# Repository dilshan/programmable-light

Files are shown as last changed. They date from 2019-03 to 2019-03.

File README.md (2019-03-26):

# Programmable Light Controller

Finished version of programmable light controller
Programmable light is a low cost and easy to build LED light controller. The main objective of this project is to design a maintenance free light which automatically on and off at the predetermined time of the day.

This light controller is based on *ATmega8* microcontroller and *DS1307* real time clock. It is designed to handle commonly available 24V - 7W LED modules. 

This is [certified open source hardware project](https://certification.oshwa.org/lk000002.html). All the design files, documentation, firmware source code are available to download at the [project source repository](https://github.com/dilshan/programmable-light). All the content of this project are distributed under the terms of the following license: 

* Hardware License: [CC BY 4.0](https://creativecommons.org/licenses/by/4.0/)
* Software License: [MIT](https://github.com/dilshan/programmable-light/blob/master/LICENSE)
* Documentation License: [CC BY 4.0](https://creativecommons.org/licenses/by/4.0/)

LK000002 (https://certification.oshwa.org/lk000002.html)

For more details check [project documentation at GitHub](https://github.com/dilshan/programmable-light/wiki).

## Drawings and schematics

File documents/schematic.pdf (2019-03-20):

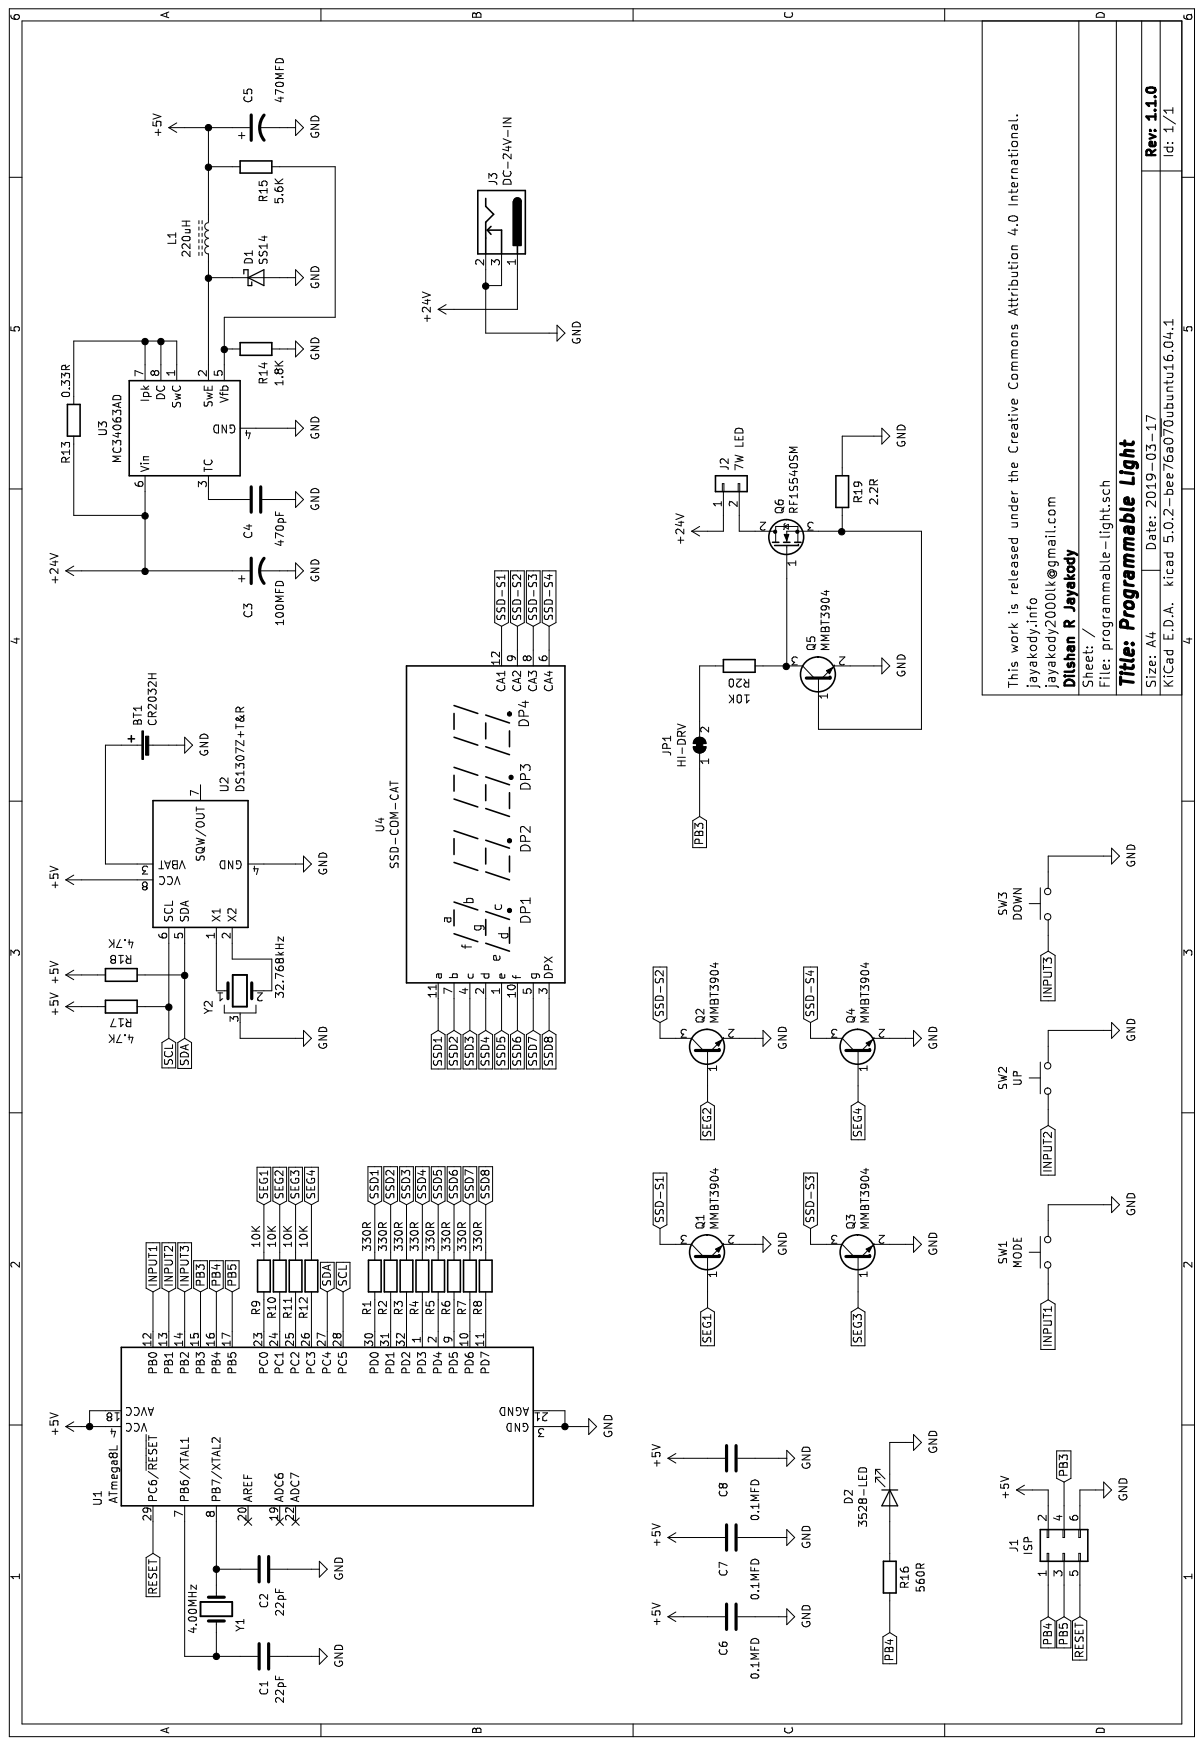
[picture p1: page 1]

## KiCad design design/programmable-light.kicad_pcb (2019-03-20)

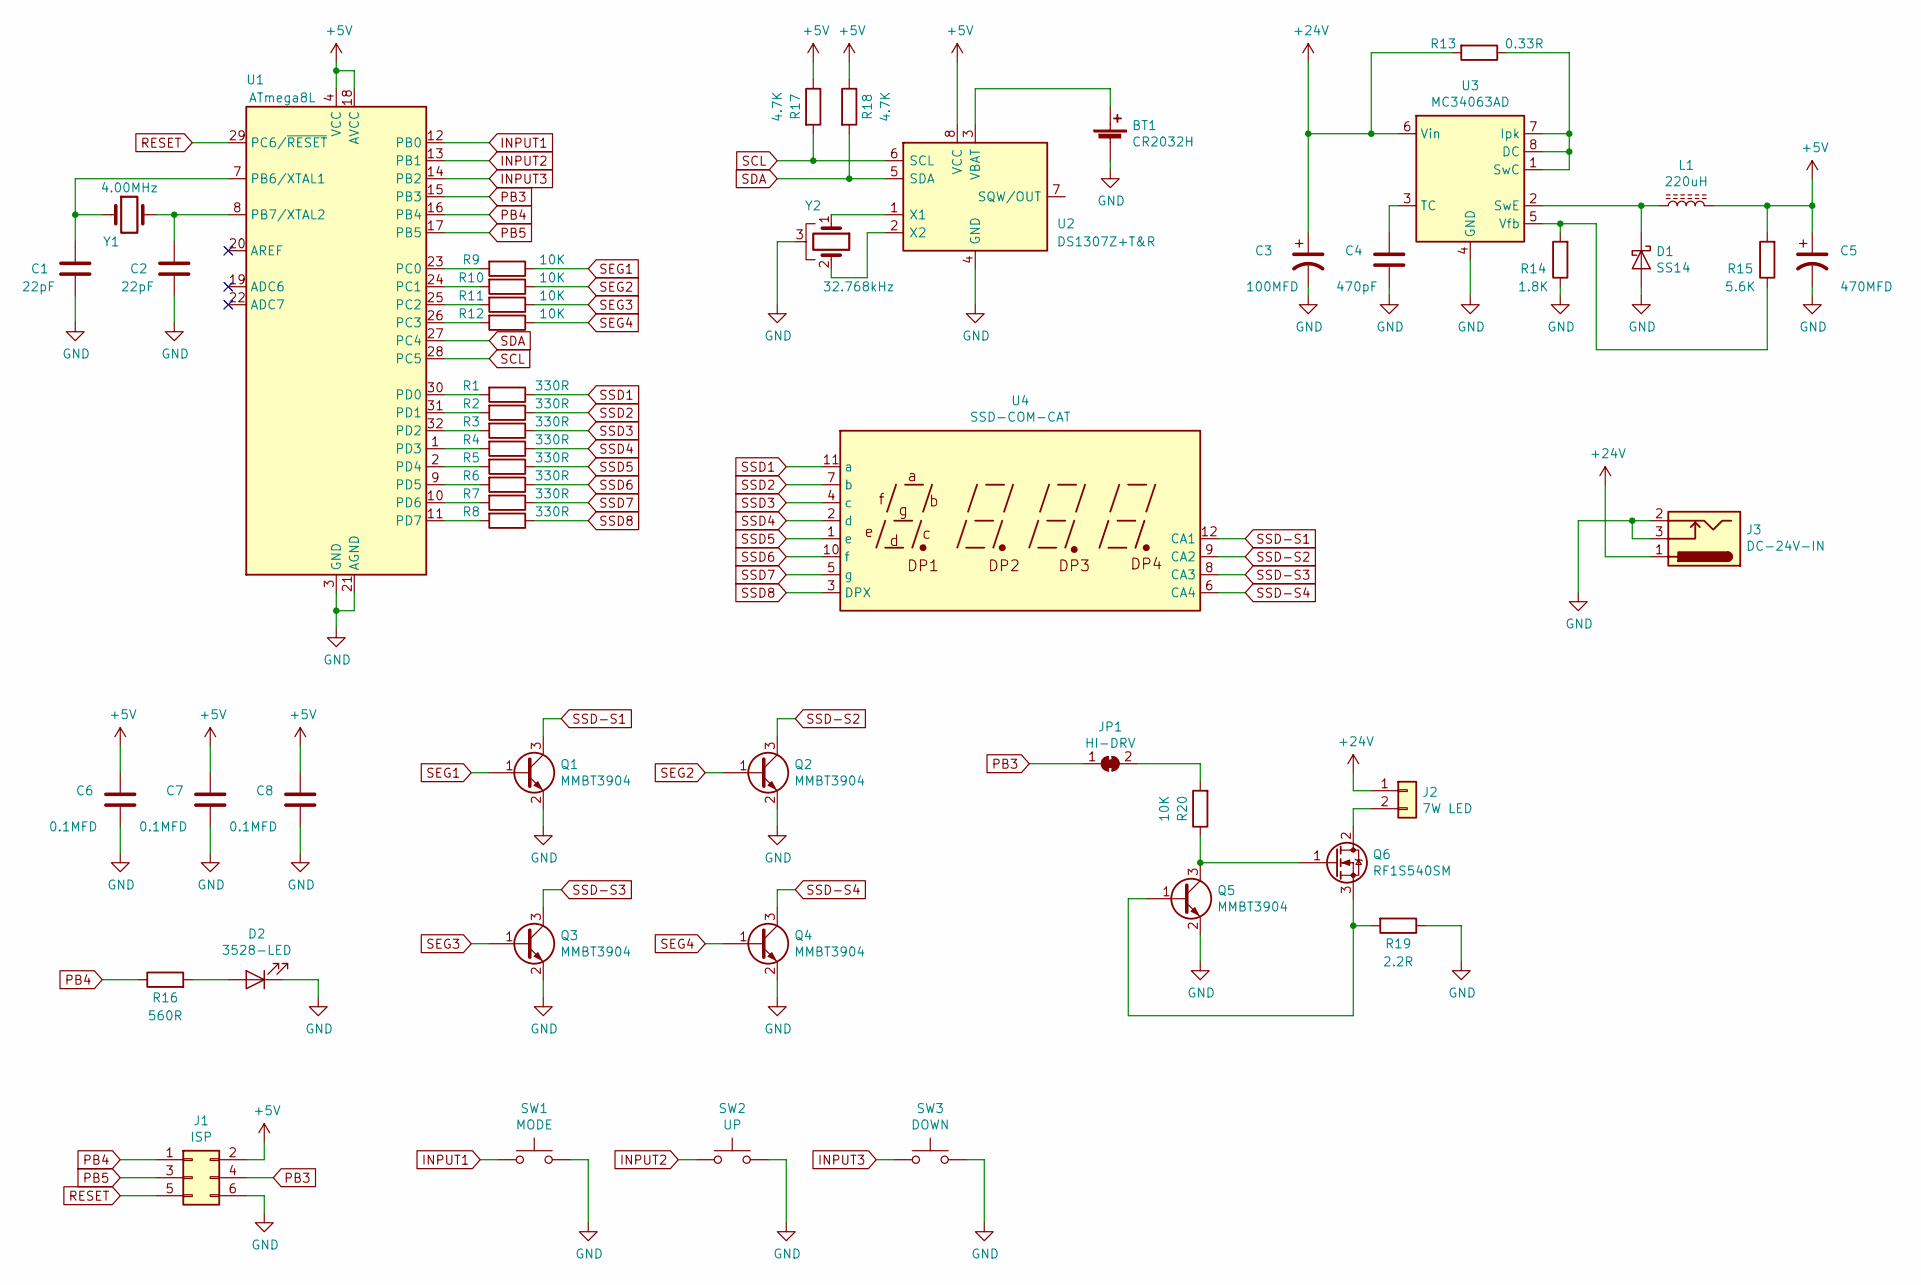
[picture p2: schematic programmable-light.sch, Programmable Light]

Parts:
BT1: CR2032H; BatteryHolder_Keystone_104_1x23mm
C1, C2: 22pF; C_0805_2012Metric
C3: 100MFD; CP_Elec_6.3x5.4
C4: 470pF; C_0805_2012Metric
C5: 470MFD; CP_Elec_10x10.5
C6, C7, C8: 0.1MFD; C_0805_2012Metric
D1: SS14; D_SMA
D2: 3528-LED; LED_1210_3225Metric
J1: ISP; PinHeader_2x03_P2.54mm_Vertical
J2: 7W LED; PhoenixContact_MCV_1,5_2-G-3.81_1x02_P3.81mm_Vertical
J3: DC-24V-IN; BarrelJack_Horizontal
JP1: HI-DRV; SolderJumper-2_P1.3mm_Bridged2Bar_RoundedPad1.0x1.5mm
L1: 220uH; L_Taiyo-Yuden_NR-80xx
Q1, Q2, Q3, Q4, Q5: MMBT3904; SOT-23
Q6: RF1S540SM; TO-263-2
R1, R2, R3, R4, R5, R6, R7, R8: 330R; R_0805_2012Metric
R9, R10, R11, R12, R20: 10K; R_0805_2012Metric
R13: 0.33R; R_2512_6332Metric
R14: 1.8K; R_0805_2012Metric
R15: 5.6K; R_0805_2012Metric
R16: 560R; R_0805_2012Metric
R17, R18: 4.7K; R_0805_2012Metric
R19: 2.2R; R_Axial_DIN0516_L15.5mm_D5.0mm_P20.32mm_Horizontal
SW1: MODE; SW_PUSH_6mm
SW2: UP; SW_PUSH_6mm
SW3: DOWN; SW_PUSH_6mm
U1: ATmega8L; TQFP-32_7x7mm_P0.8mm
U2: DS1307Z+T&R; SOIC-8_3.9x4.9mm_P1.27mm
U3: MC34063AD; SOIC-8_3.9x4.9mm_P1.27mm
U4: SSD-COM-CAT; CA56-12CGKWA
Y1: 4.00MHz; Crystal_SMD_HC49-SD
Y2: 32.768kHz; Crystal_C26-LF_D2.1mm_L6.5mm_Horizontal_1EP_style2

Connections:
+5V: C5.1, C6.1, C7.1, C8.1, J1.2, L1.2, R15.2, R17.1, R18.1, U1.4 (VCC), U1.6 (VCC), U1.18 (AVCC), U2.8 (VCC)
+24V: C3.1, J2.1, J3.1, R13.2, U3.6 (Vin)
GND: BT1.2 (-), C1.2, C2.2, C3.2, C4.2, C5.2, C6.2, C7.2, C8.2, D1.2 (A), D2.1 (K), J1.6, J3.2, J3.3, Q1.2 (E), Q2.2 (E), Q3.2 (E), Q4.2 (E), Q5.2 (E), R14.1, R19.1, SW1.2, SW2.2, SW3.2, U1.3 (GND), U1.5 (GND), U1.21 (AGND), U2.4 (GND), U3.4 (GND), Y2.3
INPUT1: SW1.1, U1.12 (PB0)
INPUT2: SW2.1, U1.13 (PB1)
INPUT3: SW3.1, U1.14 (PB2)
unnamed: BT1.1 (+), U2.3 (VBAT)
unnamed: C1.1, U1.7 (PB6/XTAL1), Y1.1
unnamed: C2.1, U1.8 (PB7/XTAL2), Y1.2
unnamed: C4.1, U3.3 (TC)
unnamed: D1.1 (K), L1.1, U3.2 (SwE)
unnamed: D2.2 (A), R16.2
unnamed: J2.2, Q6.2 (D)
unnamed: JP1.2 (B), R20.2
unnamed: Q5.1 (B), Q6.3 (S), R19.2
unnamed: Q5.3 (C), Q6.1 (G), R20.1
unnamed: R1.2, U1.30 (PD0)
unnamed: R2.2, U1.31 (PD1)
unnamed: R3.2, U1.32 (PD2)
unnamed: R4.2, U1.1 (PD3)
unnamed: R5.2, U1.2 (PD4)
unnamed: R6.2, U1.9 (PD5)
unnamed: R7.2, U1.10 (PD6)
unnamed: R8.2, U1.11 (PD7)
unnamed: R9.2, U1.23 (PC0)
unnamed: R10.2, U1.24 (PC1)
unnamed: R11.2, U1.25 (PC2)
unnamed: R12.2, U1.26 (PC3)
unnamed: R13.1, U3.1 (SwC), U3.7 (Ipk), U3.8 (DC)
unnamed: R14.2, R15.1, U3.5 (Vfb)
unnamed: U2.1 (X1), Y2.1
unnamed: U2.2 (X2), Y2.2
PB3: J1.4, JP1.1 (A), U1.15 (PB3)
PB4: J1.1, R16.1, U1.16 (PB4)
PB5: J1.3, U1.17 (PB5)
RESET: J1.5, U1.29 (PC6/~RESET)
SCL: R17.2, U1.28 (PC5), U2.6 (SCL)
SDA: R18.2, U1.27 (PC4), U2.5 (SDA)
SEG1: Q1.1 (B), R9.1
SEG2: Q2.1 (B), R10.1
SEG3: Q3.1 (B), R11.1
SEG4: Q4.1 (B), R12.1
SSD1: R1.1, U4.11 (a)
SSD2: R2.1, U4.7 (b)
SSD3: R3.1, U4.4 (c)
SSD4: R4.1, U4.2 (d)
SSD5: R5.1, U4.1 (e)
SSD6: R6.1, U4.10 (f)
SSD7: R7.1, U4.5 (g)
SSD8: R8.1, U4.3 (DPX)
SSD-S1: Q1.3 (C), U4.12 (CA1)
SSD-S2: Q2.3 (C), U4.9 (CA2)
SSD-S3: Q3.3 (C), U4.8 (CA3)
SSD-S4: Q4.3 (C), U4.6 (CA4)

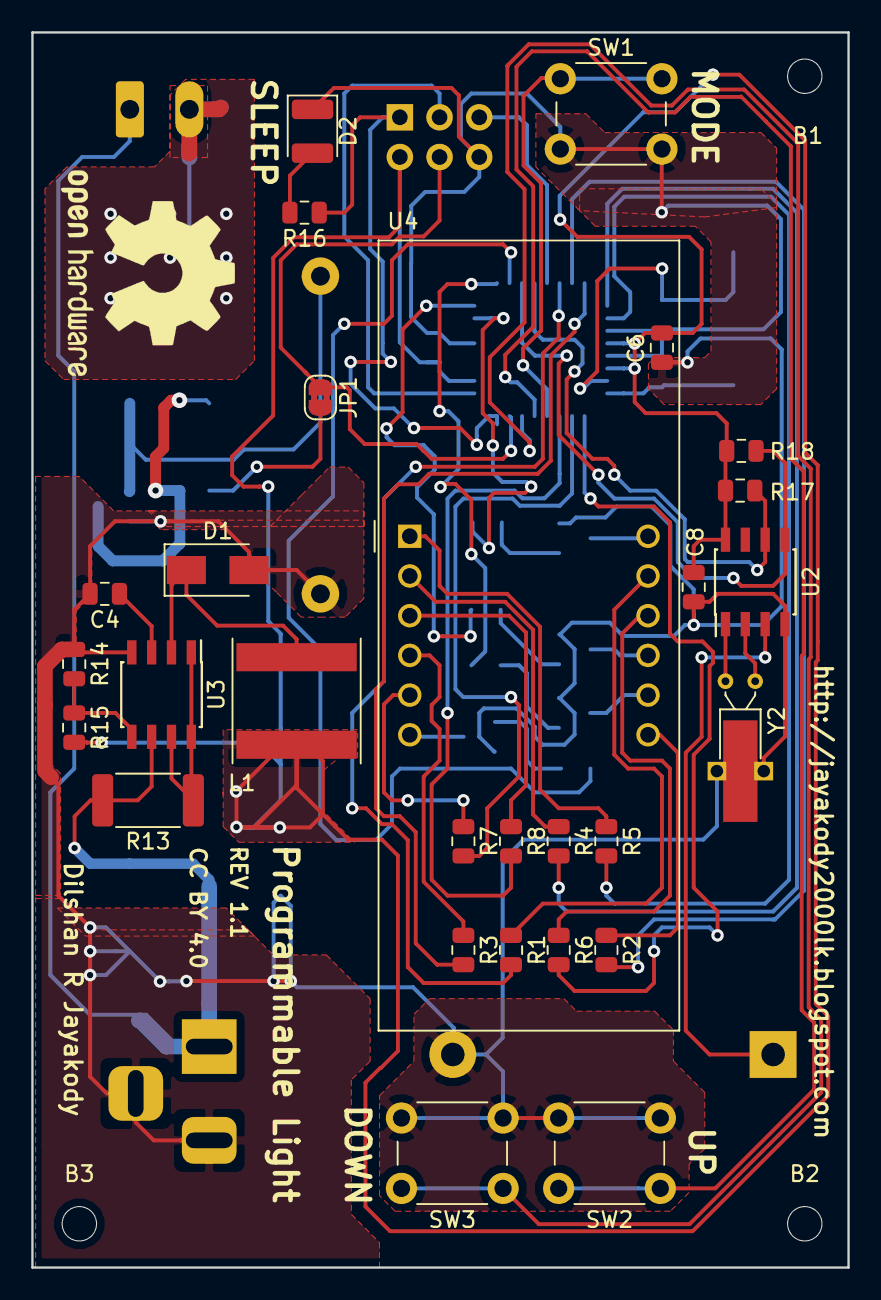
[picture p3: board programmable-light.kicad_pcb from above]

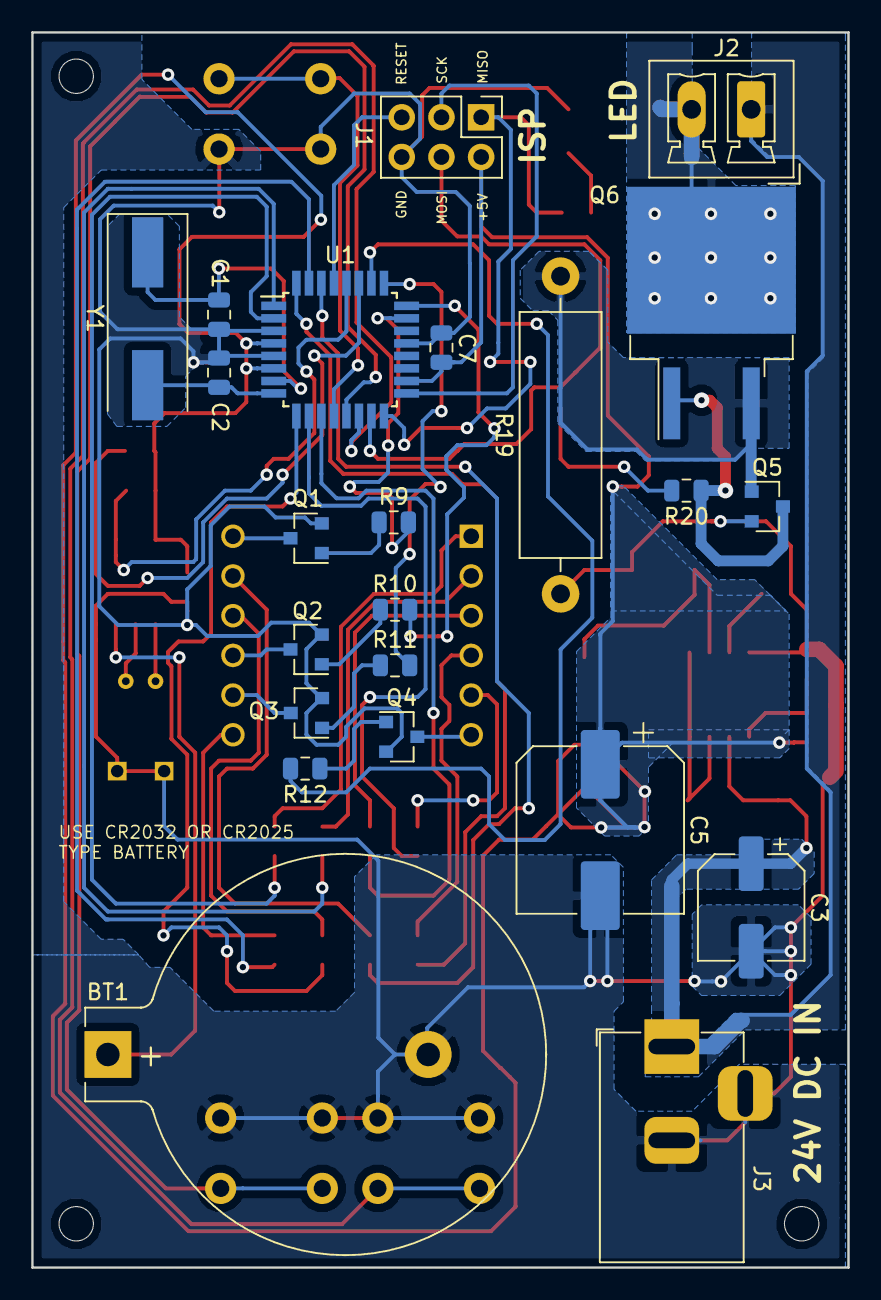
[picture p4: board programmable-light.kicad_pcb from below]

Board: 2 copper layers, 52.2 x 79.0 mm, 54 parts (23 on the bottom side), 54 nets.

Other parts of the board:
B1, B2, B3: M2-1; MountingHole_2.2mm_M2

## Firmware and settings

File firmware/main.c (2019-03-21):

/*************************************************************************
* Title:	ATmega8 Firmware for programmable light controller.
* Author:	Dilshan R Jayakody <jayakody2000lk@gmail.com>
* Project:	Programmable LED controller.
* Homepage:	https://github.com/dilshan/programmable-light
* File:     main.c
* Info:		Main firmware module with applicaion entry point.
* Compiler: AVR GCC 5.4.0 (AVR 8-bit GNU Toolchain 3.6.1)
* Target:   ATmega8L / ATmega8A
**************************************************************************/

#include "sysbasedef.h"
#include "main.h"
#include "displaymodule.h"
#include "rtcmodule.h"
#include "memmodule.h"
#include "timemodule.h"

#include <avr/io.h>
#include <util/delay.h>	
#include <avr/interrupt.h>

INT main(VOID)
{
	UCHAR currentButtonState = 0x07;
	UCHAR lastButtonState = 0x07;
	UCHAR optionButtonCycles = 0;
	
	initSystem();
	
	// Load user defined start and end time from EEPROM.
	readTimeFromMemory(&_startTime, 0);
	readTimeFromMemory(&_endTime, 4);
	
	// Check for valid start and end time.
	IS_VALID_EEPROM_VALUE(_startTime.hours);
	IS_VALID_EEPROM_VALUE(_startTime.minutes);
	IS_VALID_EEPROM_VALUE(_startTime.seconds);
	
	IS_VALID_EEPROM_VALUE(_endTime.hours);
	IS_VALID_EEPROM_VALUE(_endTime.minutes);
	IS_VALID_EEPROM_VALUE(_endTime.seconds);
	
	while (1) 
    {
		currentButtonState = (PINB & 0x07);
		
		// Check for <option button> press event.
		if(IS_BUTTON_PRESSED(currentButtonState, 0x01, lastButtonState))
		{
			optionButtonCycles = 0;
			_ssdMode = SSD_DISPLAY_TIME;
			startSleepTimer();
		}
		
		// Check for <up button> press event.
		if(IS_BUTTON_PRESSED(currentButtonState, 0x02, lastButtonState))
		{
			optionButtonCycles = 0;
			_ssdMode = SSD_DISPLAY_START;
			startSleepTimer();
		}
		
		// Check for <down button> press event.
		if(IS_BUTTON_PRESSED(currentButtonState, 0x04, lastButtonState))
		{
			optionButtonCycles = 0;
			_ssdMode = SSD_DISPLAY_END;
			startSleepTimer();
		}
		
		// Clear timer if system is idle for long time.
		if(!_sleepTimer)
		{
			_ssdMode = SSD_DISPLAY_NONE;
		}
		
		// Count <option button> hold time.
		if((currentButtonState & 0x01) == 0x00)
		{
			optionButtonCycles++;
		}
		
		// Long press of <option button> should open settings menu.
		if(optionButtonCycles > LONG_PRESS_LIMIT)
		{
			optionButtonCycles = 0;

			updateSleepLED(FALSE);
			showConfigurationOption();
			
			// Update system time immediately. 
			getSystemTime(&_sysTime);
			
			// Restore blink status and related variables.
			setEditSegment(NO_EDIT_SEGMENT);
			setBlickState(TRUE);
			
			// Reset button status.
			currentButtonState = 0x07;
			lastButtonState = currentButtonState;
			continue;
		}
		
		// Update seven segment display based on current display mode.
		switch(_ssdMode)
		{
			case SSD_DISPLAY_TIME:
				sysTimeToDisplayBuffer(&_sysTime, &_displayBuffer);
				updateSleepLED(FALSE);
				break;
			case SSD_DISPLAY_NONE:
				// Clear entire display buffer and shutdown seven segment display.
				clearDisplay(_displayBuffer.valueBuffer, SSD_SIZE);
				updateSleepLED(TRUE);
				_displayBuffer.decimalPoint = 0xFF;
				break;
			case SSD_DISPLAY_START:
				sysTimeToDisplayBuffer(&_startTime, &_displayBuffer);
				updateSleepLED(FALSE);
				_displayBuffer.decimalPoint = 0x01;
				break;
			case SSD_DISPLAY_END:
				sysTimeToDisplayBuffer(&_endTime, &_displayBuffer);
				updateSleepLED(FALSE);
				_displayBuffer.decimalPoint = 0x01;
				break;
		}
		
		lastButtonState = currentButtonState;
		
		_delay_ms(60);
    }
}

/*************************************************************************
 Set state of the sleep LED.
 
 isActive: Set this parameter to TRUE to turn on the LED.
 
 Return: None
*************************************************************************/
VOID updateSleepLED(UCHAR isActive)
{
	if((isActive == TRUE) && (_isLightActive == FALSE))
	{
		PORTB |= (1 << PB4);
	}
	else
	{
		PORTB &= ~(1 << PB4);
	}
}

/*************************************************************************
 Function to edit specified time data structure.
 
 editBuffer: Instance of the time structure to modify.
 
 Return: None
*************************************************************************/
VOID editTimeValue(PTIME editBuffer)
{
	UCHAR editSegmentId = 0;
	UCHAR tempSeconds;
	UCHAR currentButtonState;
	UCHAR lastButtonState = 0x07;
	UCHAR maxNumber;
	
	// Activate edit mode in display buffer.
	setEditSegment(editSegmentId);
	_isBlink = TRUE;
	_blinkState = TRUE;
	
	// Set seconds to odd number to activate the decimal indicator.
	tempSeconds = editBuffer->seconds;
	editBuffer->seconds = 1;
	sysTimeToDisplayBuffer(editBuffer, &_displayBuffer);
	
	// Wait until user release the pushed button(s).
	waitForButtonRelease();
	startSleepTimer();
	
	while(1)
	{
		currentButtonState = (PINB & 0x07);
		
		// Clear timer if system is idle for long time.
		if(!_sleepTimer)
		{
			// Exit edit mode without saving the changes.
			setEditSegment(NO_EDIT_SEGMENT);
			setBlickState(FALSE);
			_blinkCounter = 0;
			_isBlink = FALSE;
			// Restore the values of time data structure.
			editBuffer->seconds = tempSeconds;
			return;
		}
		
		// Check for <option button> press event.
		if(IS_BUTTON_PRESSED(currentButtonState, 0x01, lastButtonState))
		{
			startSleepTimer();
			
			if(editSegmentId < 3)
			{
				// Move to next segment.
				setEditSegment(++editSegmentId);
				
				// If hour is beyond 20hr we need to correct 2nd digit of the existing hour.
				if((editSegmentId == 1) && (_displayBuffer.valueBuffer[0] == 2) && (_displayBuffer.valueBuffer[1] >= 4))
				{
					_displayBuffer.valueBuffer[1] = 3;
				}
			}
			else
			{
				// Exit edit mode.
				setEditSegment(NO_EDIT_SEGMENT);
				setBlickState(FALSE);
				_blinkCounter = 0;
				_isBlink = FALSE;
				// Update time structure with modified value.
				editBuffer->hours = _displayBuffer.valueBuffer[1] + (_displayBuffer.valueBuffer[0] * 10);
				editBuffer->minutes = _displayBuffer.valueBuffer[3] + (_displayBuffer.valueBuffer[2] * 10);
				editBuffer->seconds = tempSeconds;
				return;
			}
		}
		
		// Check for <up button> press event.
		if(IS_BUTTON_PRESSED(currentButtonState, 0x02, lastButtonState))
		{
			startSleepTimer();
			
			switch(editSegmentId)
			{
				case 0:
					// Modify first digit of the hour and it allows only 0, 1 and 2.
					_displayBuffer.valueBuffer[0] = (_displayBuffer.valueBuffer[0] < 2) ? (_displayBuffer.valueBuffer[0] + 1) : 0;
					break;
				case 1:
					// Modify second digit of the hour. If first digit is 2 then this allows only 0..3, otherwise this allows 0..9
					maxNumber = (_displayBuffer.valueBuffer[0] == 2) ? 3 : 9;
					_displayBuffer.valueBuffer[1] = (_displayBuffer.valueBuffer[1] < maxNumber) ? (_displayBuffer.valueBuffer[1] + 1) : 0;
					break;
				case 2:
					// Modify first digit of the minutes.
					_displayBuffer.valueBuffer[2] = (_displayBuffer.valueBuffer[2] < 5) ? (_displayBuffer.valueBuffer[2] + 1) : 0;
					break;
				case 3:
					// Modify second digit of the minutes.
					_displayBuffer.valueBuffer[3] = (_displayBuffer.valueBuffer[3] < 9) ? (_displayBuffer.valueBuffer[3] + 1) : 0;
					break;
			}
		}
		
		// Check for <down button> press event.
		if(IS_BUTTON_PRESSED(currentButtonState, 0x04, lastButtonState))
		{
			startSleepTimer();
			
			switch(editSegmentId)
			{
				case 0:
					// Modify first digit of the hour and it allows only 0, 1 and 2.
					_displayBuffer.valueBuffer[0] = (_displayBuffer.valueBuffer[0] != 0) ? (_displayBuffer.valueBuffer[0] - 1) : 2;
					break;
				case 1:
					// Modify second digit of the hour. If first digit is 2 then this allows only 0..3, otherwise this allows 0..9
					maxNumber = (_displayBuffer.valueBuffer[0] == 2) ? 3 : 9;
					_displayBuffer.valueBuffer[1] = (_displayBuffer.valueBuffer[1] != 0) ? (_displayBuffer.valueBuffer[1] - 1) : maxNumber;
					break;
				case 2:
					// Modify first digit of the minutes.
					_displayBuffer.valueBuffer[2] = (_displayBuffer.valueBuffer[2] != 0) ? (_displayBuffer.valueBuffer[2] - 1) : 5;
					break;
				case 3:
					// Modify second digit of the minutes.
					_displayBuffer.valueBuffer[3] = (_displayBuffer.valueBuffer[3] != 0) ? (_displayBuffer.valueBuffer[3] - 1) : 9;
					break;
			}
		}
		
		lastButtonState = currentButtonState;
		_delay_ms(50);
	}
}

/*************************************************************************
 Function to handle options menu and related user inputs.
 
 Return: None
*************************************************************************/
VOID showConfigurationOption()
{
	MENU_MODE currentMode = SSD_MENU_TIME;
	UCHAR currentButtonState;
	UCHAR lastButtonState = 0x07;

	// Update display buffer with current mode (SSD_MENU_TIME).
	textToDisplay('S','Y','S',' ', &_displayBuffer);
	
	// Wait until user release the pushed button(s).
	waitForButtonRelease();
	startSleepTimer();
	
	// Start main service loop to handle options related activities.
	while(1)
	{
		currentButtonState = (PINB & 0x07);
		
		// Check for menu timeouts to clear the menu.
		if(!_sleepTimer)
		{
			return;
		}
		
		// Check for <option button> press event.
		if(IS_BUTTON_PRESSED(currentButtonState, 0x01, lastButtonState))
		{
			startSleepTimer();
			
			switch(currentMode)
			{
				case SSD_MENU_TIME:
					// Configure RTC with modified value.
					editTimeValue(&_sysTime);
					setSystemTime(&_sysTime);
					break;
				case SSD_MENU_ON_TIME:
					editTimeValue(&_startTime);
					saveTimeToMemory(&_startTime, 0);
					break;
				case SSD_MENU_OFF_TIME:
					editTimeValue(&_endTime);
					saveTimeToMemory(&_endTime, 4);
					break;
				case SSD_MENU_EXIT:
					// Exit from options menu.
					return;
			}
			
			// Reset button status.
			currentButtonState = 0x07;
			lastButtonState = currentButtonState;
			continue;
		}
		
		// Check for <up button> press event.
		if(IS_BUTTON_PRESSED(currentButtonState, 0x02, lastButtonState))
		{
			startSleepTimer();
			
			switch(currentMode)
			{
				case SSD_MENU_TIME:
					currentMode = SSD_MENU_ON_TIME;
					break;
				case SSD_MENU_ON_TIME:
					currentMode = SSD_MENU_OFF_TIME;
					break;
				case SSD_MENU_OFF_TIME:
					currentMode = SSD_MENU_EXIT;
					break;
				case SSD_MENU_EXIT:
					currentMode = SSD_MENU_TIME;
					break;
			}
		}
		
		// Check for <down button> press event.
		if(IS_BUTTON_PRESSED(currentButtonState, 0x04, lastButtonState))
		{
			startSleepTimer();
			
			switch(currentMode)
			{
				case SSD_MENU_TIME:
					currentMode = SSD_MENU_EXIT;
					break;
				case SSD_MENU_ON_TIME:
					currentMode = SSD_MENU_TIME;
					break;
				case SSD_MENU_OFF_TIME:
					currentMode = SSD_MENU_ON_TIME;
					break;
				case SSD_MENU_EXIT:
					currentMode = SSD_MENU_OFF_TIME;
					break;
			}
		}
			
		// Update seven segment display based on current menu mode.
		switch(currentMode)
		{
			case SSD_MENU_TIME:
				textToDisplay('S','Y','S',' ', &_displayBuffer);
				break;
			case SSD_MENU_ON_TIME:
				textToDisplay('O','N',' ',' ', &_displayBuffer);
				break;
			case SSD_MENU_OFF_TIME:
				textToDisplay('O','F','F',' ', &_displayBuffer);
				break;
			case SSD_MENU_EXIT:
				textToDisplay(' ','-','-',' ', &_displayBuffer);
				break;
		}
		
		lastButtonState = currentButtonState;
		_delay_ms(50);
	}
}

/*************************************************************************
 Interrupt service routine for Timer2. This timer is mainly used to call 
 RTC with specific intervals to update the system time.
 
 Return: None
*************************************************************************/
ISR(TIMER2_OVF_vect)
{
	// Disable timer2 interrupt and start requesting data from RTC.
	TIMSK &= ~( 1 << TOIE2);
	
	if((++_rtcRefreshCounter) == 20)
	{
		getSystemTime(&_sysTime);
		
		// Check for light on condition.
		_isLightActive = isLightActive(&_sysTime, &_startTime, &_endTime);
		if(_isLightActive == TRUE)
		{
			// Turn on master light.
			PORTB |= (1 << PB3);
		}
		else 
		{
			// Turn off master light.
			PORTB &= ~(1 << PB3);
		}
		
		_rtcRefreshCounter = 0;
	}
	
	if(_isBlink == TRUE)
	{
		if((++_blinkCounter) == 10)
		{
			_blinkState = ~_blinkState;
			setBlickState(_blinkState);
			_blinkCounter = 0;
		}
	}
	
	// Reset timer2 counter and enable the interrupt.
	TIMSK |= (1 << TOIE2);
	TCNT2 = 0;
}

/*************************************************************************
 Interrupt service routine for Timer0. This timer is used to update 
 seven segment display with display buffer content.
 
 Return: None
*************************************************************************/
ISR(TIMER0_OVF_vect)
{
	// Disable timer0 interrupt and refresh seven segment display.
	TIMSK &= ~( 1 << TOIE0);
	
	// Update seven segment display based on current display buffer content.
	setDisplayValueSet(&_displayBuffer);
	
	// Reset timer0 counter and enable the interrupt.
	TIMSK |= (1 << TOIE0);
	TCNT0 = 232;
}

/*************************************************************************
 Interrupt service routine for Timer1. This timer is used to detect 
 system idle state.
 
 Return: None
*************************************************************************/
ISR(TIMER1_OVF_vect)
{
	// Disable timer1 interrupt and refresh seven segment display.
	TIMSK &= ~( 1 << TOIE1);
	
	// Update sleep counter for display / menu timeouts.
	if(_sleepTimer > 0)
	{
		_sleepTimer--;
		
		// Reset timer1 counter and enable the interrupt.
		TIMSK |= (1 << TOIE1);
		TCNT1 = 0;
	}
}

/*************************************************************************
 Enable sleep timer to determine system idle state.
 
 Return: None
*************************************************************************/
VOID startSleepTimer()
{
	_sleepTimer = SLEEP_TIMEOUT;
	TIMSK |= (1 << TOIE1);
	TCNT1 = 0;
}

/*************************************************************************
 Wait until user release the input button(s).
 
 Return: None
*************************************************************************/
VOID waitForButtonRelease()
{
	while(1)
	{
		if((PINB & 0x07) == 0x07)
		{
			_delay_ms(500);
			break;
		}
		
		_delay_ms(50);
	}
	
	_delay_ms(150);
}

/*************************************************************************
 Initialize MCU by setting up the default values for ports and
 system registers.  
 
 Return: None
*************************************************************************/
VOID initSystem()
{
	// Shutdown unused peripherals of this MCU.
	ADCSRA = 0x00;
	
	// Set PORTC and PORTD as an output ports (mainly used for seven segment display).
	DDRD = 0xFF;
	DDRC = 0xFF;
	DDRB = 0xF8;
	
	// Set default state of the ports.
	PORTD = 0x00;
	PORTC = 0x00;
	PORTB = 0x07;
	
	// Enable timer0 with to handle button inputs.
	TCNT0 = 232;
	TCCR0 |= (1 << CS02);
	
	// Enable timer2 to handle RTC scans.
	TCNT2 = 0;
	TCCR2 |= (1 << CS22) | (1 << CS21) | (1 << CS22);
	
	// Enable timer1 with long time durations.
	TCNT1 = 0;
	TCCR1B |= (1 << CS12);
	
	_delay_ms(10);
	
	_rtcRefreshCounter = 0;
	_ssdMode = SSD_DISPLAY_NONE;
	
	_blinkCounter = 0;
	_isBlink = FALSE;
	_sleepTimer = 0;
	_isLightActive = FALSE;
	
	// Clear seven segment related data structures.
	clearDisplay(_displayBuffer.valueBuffer, SSD_SIZE);
	_displayBuffer.decimalPoint = 0xFF;
	
	// Reset editor related parameters.
	setEditSegment(NO_EDIT_SEGMENT);
	setBlickState(TRUE);
	
	// Initialize I2C to communicate with DS1307 RTC.
	initRTCModule();
	_delay_ms(20);
	
	// Make sure that RTC runs correctly. If RTC battery backup fails it returns
	// garbage values, and this code block fix it by reset the RTC to 00:00:00.
	getSystemTime(&_sysTime);
	if((_sysTime.hours > 23) || (_sysTime.minutes > 59) || (_sysTime.seconds > 59))
	{
		// Ignore time setup on brownout resets. This check is required to work with some PSUs. 
		if((MCUCSR & 0x04) == 0x00)
		{
			// Reset RTC time to 00:00:00.
			_sysTime.hours = 0;
			_sysTime.minutes = 0;
			_sysTime.seconds = 0;
					
			setSystemTime(&_sysTime);
			_delay_ms(20);
		}
	}
	
	// Setup required interrupts.
	TIMSK |= (1 << TOIE0) | (1 << TOIE2) | (1 << TOIE1);
	sei();
}

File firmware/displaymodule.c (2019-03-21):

/*************************************************************************
* Title:	ATmega8 Firmware for programmable light controller.
* Author:	Dilshan R Jayakody <jayakody2000lk@gmail.com>
* Project:	Programmable LED controller.
* Homepage:	https://github.com/dilshan/programmable-light
* File:     displaymodule.c
* Info:		Seven segment display related routines.
* Compiler: AVR GCC 5.4.0 (AVR 8-bit GNU Toolchain 3.6.1)
* Target:   ATmega8L / ATmega8A
**************************************************************************/

#include "sysbasedef.h"
#include "displaymodule.h"

#include <util/delay.h>
#include <avr/io.h>

// Define port outputs for all digits.
#define DIGIT_0		0x3F
#define DIGIT_1		0x06
#define DIGIT_2		0x5B
#define DIGIT_3		0x4F
#define DIGIT_4		0x66
#define DIGIT_5		0x6D
#define DIGIT_6		0x7D
#define DIGIT_7		0x07
#define DIGIT_8		0x7F
#define DIGIT_9		0x6F

// Define port outputs for English letters.
#define LETTER_N	0x54
#define LETTER_F	0x71
#define LETTER_E	0x79
#define LETTER_D	0x5E
#define LETTER_O	0x3F
#define LETTER_I	0x04
#define LETTER_T	0x78
#define LETTER_X	0x76
#define LETTER_Y	0x6E
#define LETTER__	0x40

// Define port output for SSD decimal indicator.
#define DECIMAL_POINT	0x80

UCHAR _editSegment = TRUE;
UCHAR _editBlink = TRUE;

/*************************************************************************
 Set currently active seven segment.

 segmentId: Active segment id starting from 0. Specify NO_EDIT_SEGMENT to
		    activate all the seven segment modules.
 
 Return: None
*************************************************************************/
VOID setEditSegment(UCHAR segmentId)
{
	_editSegment = segmentId;
}

/*************************************************************************
 Setup blink state of the seven segment display.

 isActive: Set this parameter to TRUE to blink the active seven segment.
 
 Return: None
*************************************************************************/
VOID setBlickState(UCHAR isActive)
{
	_editBlink = isActive;
}

/*************************************************************************
 Set display of the active seven segment display. 

 displayValue: Value to display on the seven segment display.

 isDeimal: set to TRUE / FALSE to activate the decimal indicator of the 
           seven segment display.
 
 Return: None
*************************************************************************/
VOID setDIsplaySegment(UCHAR displayValue, UCHAR isDeimal)
{
	switch(displayValue)	
	{
		// Digit mapping from 0 to 9.
		case 0x00:
			PORTD = DIGIT_0;
			break;
		case 0x01:
			PORTD = DIGIT_1;
			break;
		case 0x02:
			PORTD = DIGIT_2;
			break;
		case 0x03:
			PORTD = DIGIT_3;
			break;
		case 0x04:
			PORTD = DIGIT_4;
			break;
		case 0x05:
		case 0x53:
			PORTD = DIGIT_5;
			break;
		case 0x06:
			PORTD = DIGIT_6;
			break;
		case 0x07:
			PORTD = DIGIT_7;
			break;
		case 0x08:
			PORTD = DIGIT_8;
			break;
		case 0x09:
			PORTD = DIGIT_9;
			break;
			
		// Start English letter mappings.
		case 0x0A:
		case 0x44:
			PORTD = LETTER_D;
			break;
		case 0x45:
		case 0x0B:
			PORTD = LETTER_E;
			break;
		case 0x46:
		case 0x0C:
			PORTD = LETTER_F;
			break;
		case 0x49:
		case 0x0D:
			PORTD = LETTER_I;
			break;
		case 0x4E:
		case 0x0E:
		case 0x4D:
			PORTD = LETTER_N;
			break;
		case 0x0F:
		case 0x4F:
			PORTD = LETTER_O;
			break;
		case 0x10:
		case 0x54:
			PORTD = LETTER_T;
			break;
		case 0x11:
		case 0x58:
			PORTD = LETTER_X;
			break;
		case 0x12:
		case 0x59:
			PORTD = LETTER_Y;
			break;
		case 0x13:
		case 0x2D:
			PORTD = LETTER__;
			break;
			
		// For other values lets clear the segment.
		default:
			PORTD = 0x00;	
	}
	
	// Check to activate decimal indicator of the seven segment display.
	if(isDeimal)
	{
		PORTD |= DECIMAL_POINT;
	}
}

/*************************************************************************
 Set display of the complete seven segment display module. 

 valueSet: Instance of the display data structure.

 Return: None
*************************************************************************/
VOID setDisplayValueSet(PDISPLAY displayInfo)
{
	UCHAR segmentId = 0;
	
	for(segmentId = 0; segmentId < SSD_SIZE; segmentId++)
	{
		setDIsplaySegment(displayInfo->valueBuffer[segmentId], (displayInfo->decimalPoint == segmentId));
		if((_editSegment != segmentId) || (_editBlink == TRUE))
		{
			PORTC = (PORTC & 0xF0) | 1 << segmentId ;
		}
		
		_delay_us(400);
		PORTC = 0x00;
	}
}

/*************************************************************************
 Fill display buffer with specified character set.

 c1...c4: Character to fill the data buffer. Specify 0xFF to shutdown the 
		  appropriate segment of SSD module.
		  
 dataBuffer: Instance of the display data structure to fill with 
			 specified character set.
 
 Return: None
*************************************************************************/
VOID textToDisplay(UCHAR c1, UCHAR c2, UCHAR c3, UCHAR c4, PDISPLAY dataBuffer)
{
	dataBuffer->decimalPoint = 0xFF;
	
	dataBuffer->valueBuffer[0] = c1;
	dataBuffer->valueBuffer[1] = c2;
	dataBuffer->valueBuffer[2] = c3;
	dataBuffer->valueBuffer[3] = c4;
}

/*************************************************************************
 Clear value content of the specified display buffer. 

 valueSet: Instance of the display data structure.

 valueSize: Number of segments to clear.
 
 Return: None
*************************************************************************/
VOID clearDisplay(PUCHAR valueSet, UCHAR valueSize)
{
	UCHAR tempPos = 0;
	while(tempPos < valueSize)	
	{
		valueSet[tempPos] = 0xFF;
		tempPos++;
	}
}

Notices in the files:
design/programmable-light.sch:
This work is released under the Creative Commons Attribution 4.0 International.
